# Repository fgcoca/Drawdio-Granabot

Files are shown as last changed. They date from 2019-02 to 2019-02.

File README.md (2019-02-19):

# Drawdio-Granabot
Esta versión de Drawdio es derivada de la de [**Jorge Frutos** (@JorFru)](https://twitter.com/JorFru_) realizada en [**UC3Music** (@UC3Music)](https://music.uc3m.es/) realizada cómo una práctica más de diseño de los alumnos de primer curso del Ciclo Formativo de Grado Superior de Mantenimiento Electrónico del IES Virgen de las Nieves y que ha pasado a formar parte de la exposición Play del Parque de las Ciencias de Granada. 

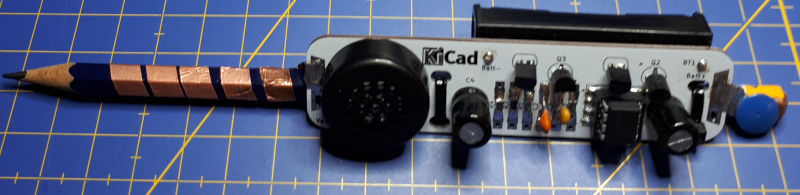
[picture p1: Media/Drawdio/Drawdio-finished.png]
Aspecto final del montaje con lápiz


 [1]: https://github.com/fgcoca/Drawdio-Granabot/blob/master/Media/Drawdio/Drawdio-finished.png

# **El diseño**
Es simplemente una versión simple de la versión de Jorge Frutos también diseñada con [Kicad 5.02](http://kicad-pcb.org/) y gracias a que su diseño es compartido de forma libre y por tanto patrimonio de la humanidad. Bajo este mismo principio de licencia CC BY SA se realiza esta versión y por tanto cualquiera de sus partes puede ser descargada, usada, cambiada, compartida y todo lo que se nos ocurra siempre bajo las condiciones establecidad en el apartado **Licencia**

Los archivos de diseño los tenemos en el enlace:

https://github.com/fgcoca/Drawdio-Granabot/tree/master/Drawdio-Granabot/KiCad%20files

Los archivos gerber están en este enlace:

https://github.com/fgcoca/Drawdio-Granabot/tree/master/Drawdio-Granabot/gerbers

las PCBs del proyecto se fabrican en [PCBWay](https://www.pcbway.com/) y están disponibles en el enlace que sigue:

https://www.pcbway.com/project/shareproject/W57189ASE4_drawdio.html

Si quieres ver lo que necesitas aquí tenemos una lista de materiales gráfica:

https://github.com/fgcoca/Drawdio-Granabot/blob/master/Drawdio-Granabot/doc/Grafic-BOM-Drawdio.pdf

Correspondiente al esquema que podemos ver en el enlace:

https://github.com/fgcoca/Drawdio-Granabot/blob/master/Drawdio-Granabot/doc/Esquema-drawdio.pdf

El aspecto de la PCB con y sin componentes por ambas caras lo vemos en las imágenes siguientes:

| Cara | Aspecto |
| --- | --- |
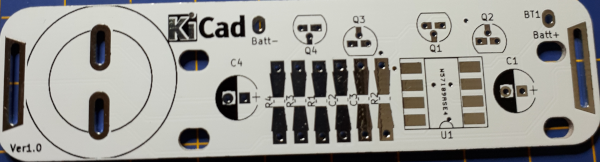
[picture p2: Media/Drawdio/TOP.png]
TOP
| TOP  |  |
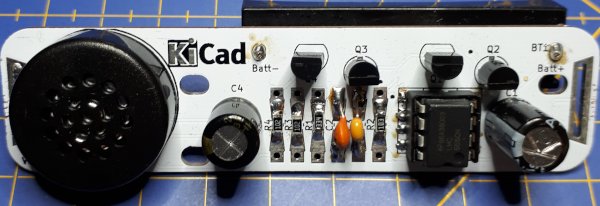
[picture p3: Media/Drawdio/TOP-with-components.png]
TOPm
| TOP montada  |  |
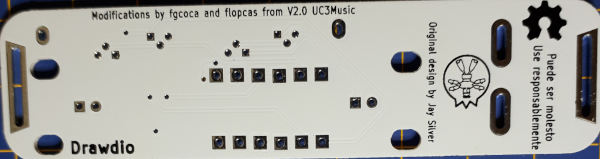
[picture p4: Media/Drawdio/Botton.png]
BOT
| BOTTON  |  |
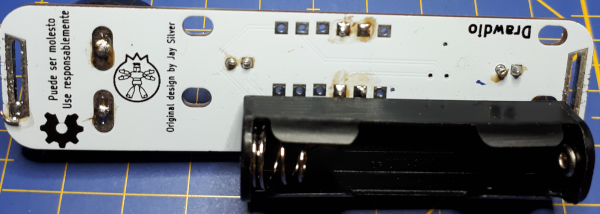
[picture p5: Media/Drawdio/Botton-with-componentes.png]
BOTm
| BOTTON montada  |  |
# **Resultado final**
Podemos ver videos del  funcionamiento en cualquiera de los enlaces siguientes:
* https://www.youtube.com/watch?v=yos-airT05g
* https://www.youtube.com/watch?v=DHovDE4k54I
* https://www.youtube.com/watch?v=34B8fDIqGeM

# **Presencia en Play**
Nuestro proyecto ha tenido el honor de ser seleccionado para formar parte de la exposición [Play. Ciencia y música](http://www.parqueciencias.com/parqueciencias/exposiciones-temporales/playcienciamusica.html) que se está celebrando actualmente (febrero de 2019) en el [Parque de las Ciencias de Granada](http://www.parqueciencias.com/parqueciencias/). Es de destacar que entre las entidades colaboradoras figura el IES Virgen de las Nieves, lo que podemos comprobar en el triptico de la exposición.

El proyecto que se lleva al parque es presentado por este cartel.

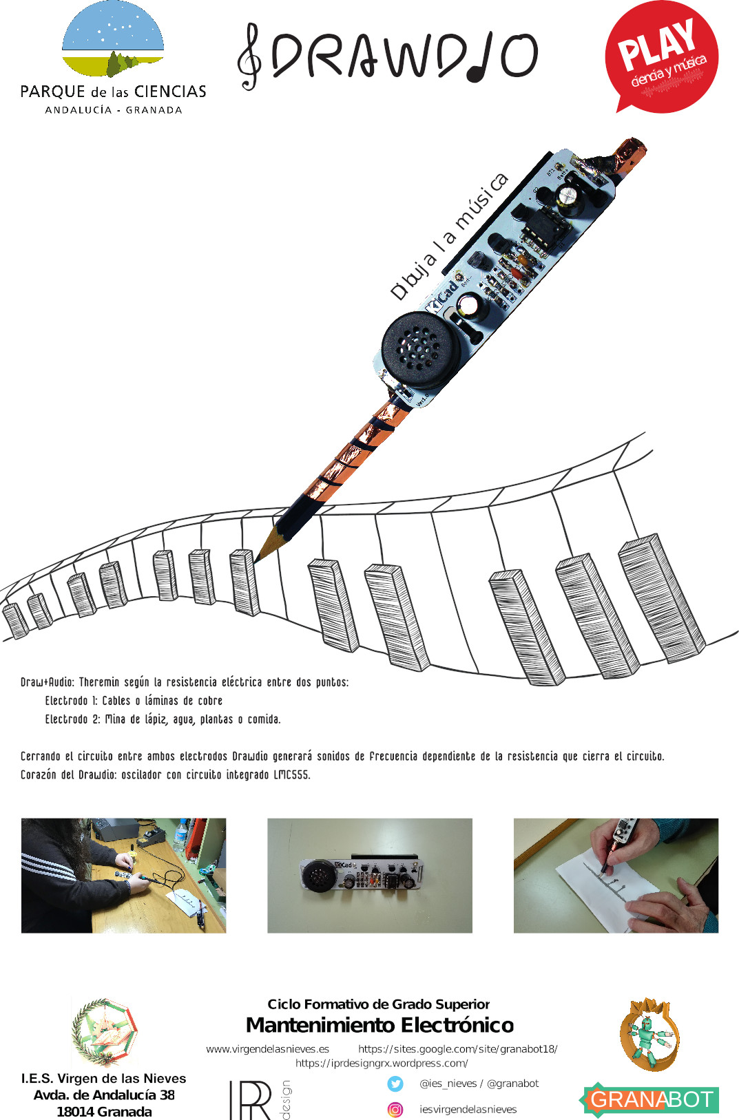
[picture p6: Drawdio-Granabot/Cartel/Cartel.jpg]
Cartel


Dicho cartel queda expuesto en el Parque y nos fotografiamos con el mismo tanto la directora del centro como yo mismo.

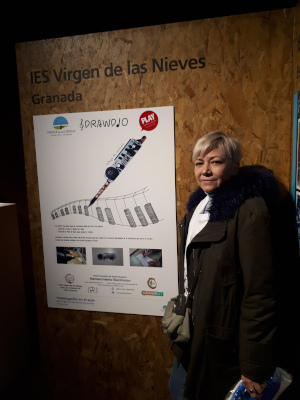
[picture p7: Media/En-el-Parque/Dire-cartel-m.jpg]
dire
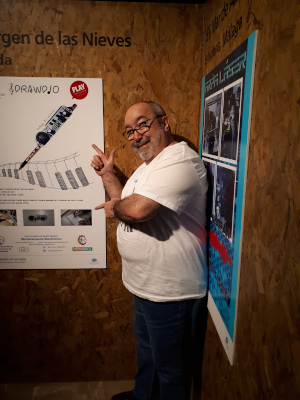
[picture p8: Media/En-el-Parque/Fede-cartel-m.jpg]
yo
|  |  |

El proyecto presentado se puede consultar en estos enlaces:
* [Proyecto Drawdio-Granabot para Play pdf](https://github.com/fgcoca/Drawdio-Granabot/blob/master/Drawdio-Granabot/doc/Proyecto-Play.pdf)
* [Proyecto Drawdio-Granabot para Play odt](https://github.com/fgcoca/Drawdio-Granabot/blob/master/Drawdio-Granabot/doc/Proyecto-Play.odt)

Para el evento de presentación del proyecto que ha tenido lugar el 14 de febrero de 2019 en el Parque se diseñó una camiseta para que el equipo de alumnos pudiera lucirla, lo que podemos apreciar en la imágenes. Todo el acto de presentación ha sido realizado por los alumnos que lo han hecho divertido e interactivo con el público asistente. Muchas gracias a todos por vuestro gran trabajo.

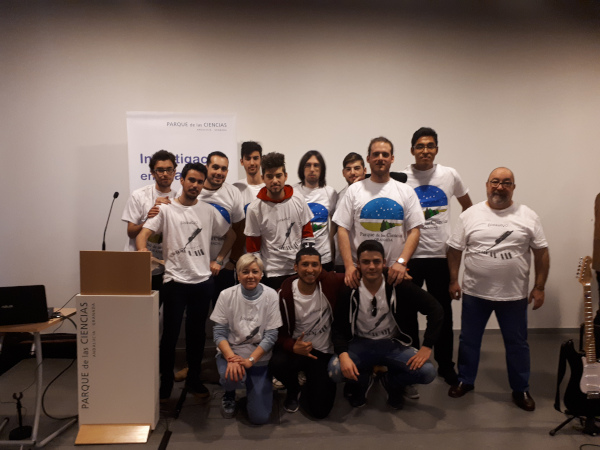
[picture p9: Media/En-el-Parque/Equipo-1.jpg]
E1

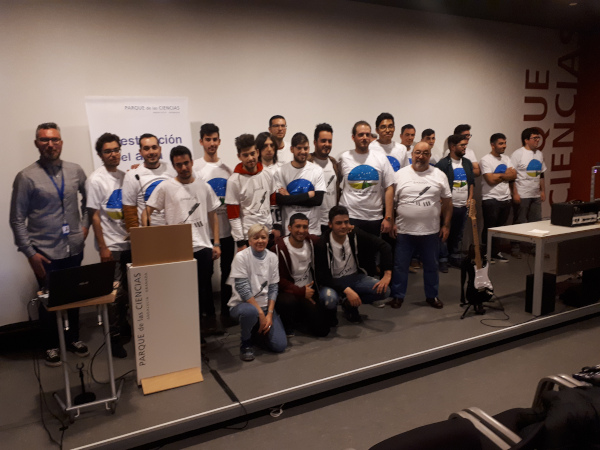
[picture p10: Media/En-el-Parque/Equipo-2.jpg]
E2

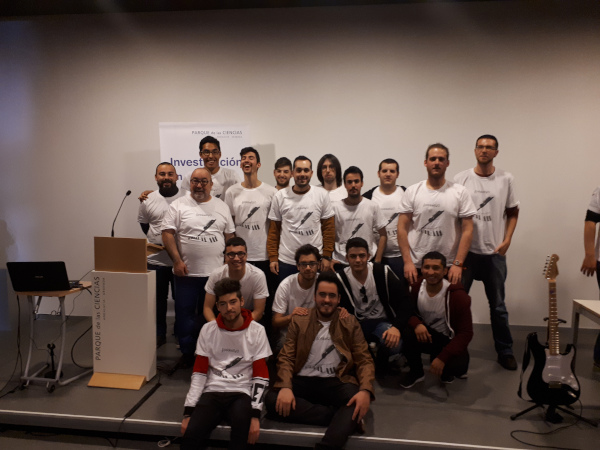
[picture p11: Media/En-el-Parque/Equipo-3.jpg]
E3

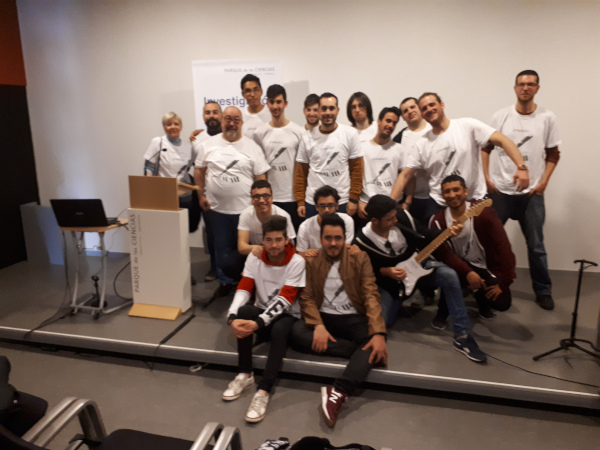
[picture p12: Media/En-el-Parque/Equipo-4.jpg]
E4


# **Autores**

[Federico Coca Caba] (https://github.com/fgcoca)

Francisco López Castro

Alumnos del grupo 1TSME

# **Créditos**
  * En primer lugar al creador original de [Drawdio](https://drawdio.com/), Jay Silver (@wakeupsilver).
  * En segundo lugar al autor de la versión en la que nos hemos basado,Jorge Frutos (@JorFru_) de [Universidad Carlos III Music](https://github.com/UC3Music/drawdio)
  * Y en tercer lugar al grupo de alumnos de 1TS de mantenimiento Electrónico del curso 18/19.

# **Licencia**
<br /> <a rel="license" href="http://creativecommons.org/licenses/by-sa/4.0/">Creative Commons Attribution-ShareAlike 4.0 International License</a>.

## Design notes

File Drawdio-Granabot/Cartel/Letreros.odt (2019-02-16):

Draw+Audio: Theremin según la resistencia eléctrica entre dos puntos:

Electrodo 1: Cables o láminas de cobre

Electrodo 2: Mina de lápiz, agua, plantas o comida.

Cerrando el circuito entre ambos electrodos Drawdio generará sonidos de frecuencia dependiente de la resistencia que cierra el circuito.

Corazón del Drawdio: oscilador con circuito integrado LMC555.

Corazón del Drawdio: oscilador con circuito integrado LMC555.

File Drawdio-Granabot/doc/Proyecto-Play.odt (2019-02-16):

Drawdio

- Cursos con los que se realizó el proyecto

Primer curso del Ciclo Formativo de Grado Superior de Mantenimiento Electrónico del IES Virgen de las Nieves de Granada.

- Como surge la idea

La idea surge de la asistencia de Federico Coca al Taller de montaje de un lápiz musical: Drawdio en la OSHDem 2018 (https://oshwdem.org/) celebrada en A Coruña el día 10 de noviembre de 2018 y que impartió el equipo UC3 Music (http://music.uc3m.es/) (grupo Music de la Universidad Carlos Tercero de Madrid).

- Toma de decisiones con el grupo de alumnos

Es bastante básica de explicar: se muestra al grupo de alumnos el funcionamiento del Drawdio montado en la OSHDem, se informa de la posibilidad de participar en el Programa Investigación en el Aula del Parque de las Ciencias con un proyecto de investigación ligado a la exposición Play. El resultado de esta propuesta es que se apunta al proyecto todo el grupo de alumnos.

- Metodología seguida

Se fundamenta en la metodología del módulo de Técnicas y Procesos de Montaje y Mantenimiento Electrónico del ciclo formativo en el que el alumnado diseña y monta circuitos.

1. Se establece el circuito electrónico para diseñar a partir de la información obtenida del repositorio drawdio (https://github.com/UC3Music/drawdio) de la UC3 Music y de la web de Jay Silver (https://drawdio.com/), su creador.
2. Los alumnos diseñan y montan la placa de circuito impreso con el circuito establecido. El aspecto final del montaje será similar al siguiente:

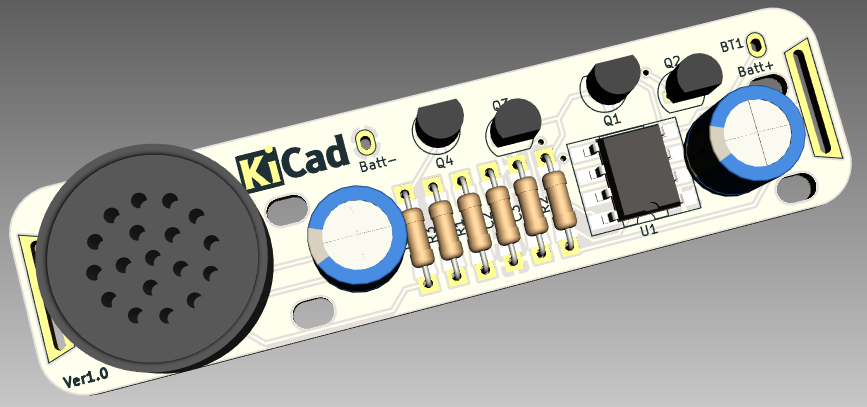
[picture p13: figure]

3. Se realizan pruebas de funcionamiento, con distintos materiales y de distintas formas, del instrumento montado. El resultado de estas pruebas se puede apreciar en el video realizado como parte de documentación del proyecto.
- Relación de alumnos participantes con indicación de los 10 miembros que conforman el equipo para la presentación en el Parque.

Orden | Nombres | Equipo
1 | Alaminos Molina, José Manuel | Presentacion
2 | Bustamante Sánchez, John Fernando | Presentacion
3 | Cara Peinado, Guillermo | Presentacion
4 | Carrillo Ureña, Rubén | Presentacion
5 | García Calvo, Manuel Enrique | Apoyo
6 | García Pérez, Javier | Apoyo
7 | Godoy Garrido, José Manuel | Apoyo
8 | López Reyes, Andrés | Presentacion
9 | López Reyes, David | Apoyo
10 | Martínez Fernández, Juan Manuel | Presentacion
11 | Montalbán Guerra, Cristóbal | Presentacion
12 | Peinado Ruiz, Ramón | Presentacion
13 | Pérez Rienda, Ismael | Presentacion
14 | Puerta Del Águila, Jesús | Presentacion
15 | Reyes Bellido, Víctor Armando | Apoyo
16 | Rodríguez Torres, Félix | Apoyo
17 | Yáñez Jerez, Francisco José | Apoyo

- Resultados obtenidos

Básicamente se trata de un pseudo instrumento músical tipo Theremin que reproduce un tono musical cuya frecuencia varía dependiendo de la resistencia eléctrica entre dos puntos.

Enrollando un cable a un lápiz tenemos un punto, otro punto es la mina del lápiz. Sujetando el Drawdio en nuestra mano pasamos a ser parte del circuito resistivo y podremos hacer sonidos de distintas frecuencias pintando con el lápiz, jugar con un chorro de agua, con comida, con otras personas y en definitiva con cualquier objeto conductor.

Es por tanto muy divertido jugar con Drawdio y llega fácilmente a todo el que lo prueba.

- Fundamentación del funcionamiento

¿Que es Drawdio?

El nombre Drawdio proviene del concepto Draw+Audio y podríamos decir que es un lápiz que “dibuja audio”

Drawdio es un pseudo instrumento musical, diseñado originalmente por Jay Silver en el MIT Media Lab (https://www.media.mit.edu/projects/drawdio/overview/). El proyecto lo encontramos en esta web (https://drawdio.com/) y en la web de Adafruit (https://learn.adafruit.com/drawdio/overview), que lo comercializa.

¿Cómo se usa?

Para que el Drawdio suene basta con completar el circuito poniendo una resistencia entre sus electrodos.

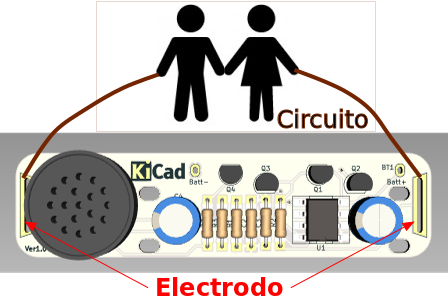
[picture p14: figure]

Esto hace que Drawdio de un sonido de una frecuencia dependiente de la resistencia que pongamos entre sus electrodos.

El montaje sobre un lápiz permite crear circuitos con dibujos ya que la mina es de grafito y este conduce la electricidad.

Otras formas de hacerlo funcionar es pintando con agua, con plantas, con varias personas, mediante el chorro de agua de un grifo, con fruta y en general mediante cualquier conductor que presente una alta impedancia.

El circuito electrónico y su descripción

Su esquema es el siguiente:

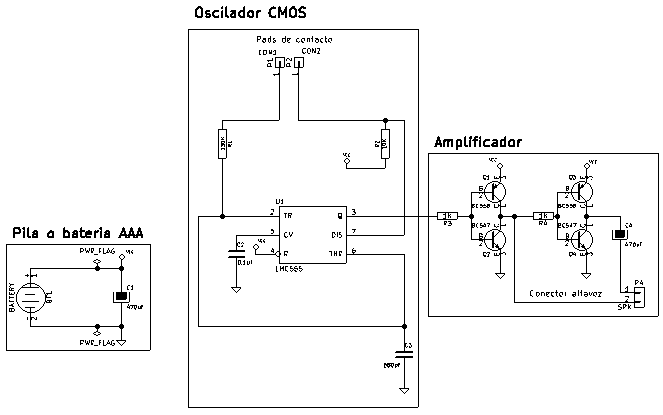
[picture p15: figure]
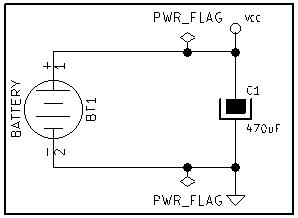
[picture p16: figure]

- Fuente de alimentación. Es la encargada de mantener todo en funcionamiento y se trata de una simple pila AAA que se coloca en un portapilas que va soldado a la PCB. En paralelo con la pila tenemos el condensador electrolítico C1 de 470 uF montado en “bypass” y se encarga de absorber cualquier rizado originado cuando el drawdio hace ruido. El circuito no está dotado de interruptor para cortar la alimentación porque esto se puede hacer fácilmente quitando la pila.

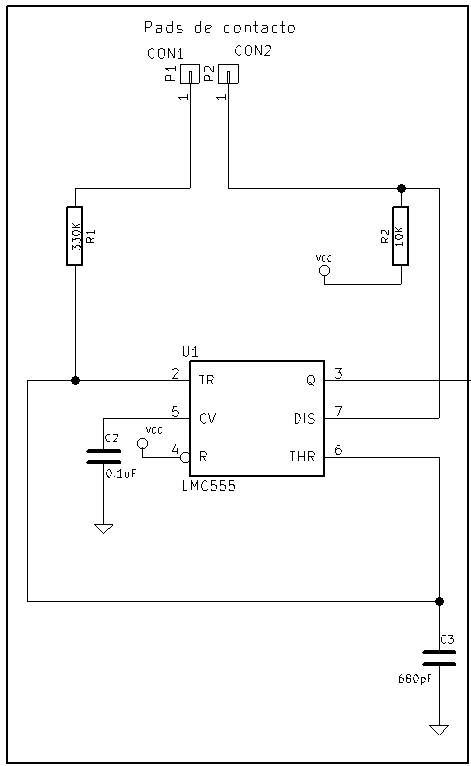
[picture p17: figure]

- El oscilador. El corazón del drawdio es un circuito integrado LMC555, que es la versión CMOS de bajo voltaje del famoso LM555. El LM555 original necesita al menos 5V para funcionar mientras que el LMC555 puede funcionar a partir de 1V.

Una de las formas más comunes de uso del 555 es como multivibrador astable, otra forma de decir un oscilador, que nos proporciona una onda cuadrada a la salida. En este enlace a Rincón Ingenieril (https://www.rinconingenieril.es/555-astable/), Enrique nos explica claramente su funcionamiento.

De forma muy resumida diremos que la frecuencia de oscilación se establece mediante dos resistencias (R1 y R2) y un condensador (C3), y como vemos los terminales de contacto ponen la resistencia que lo hace funcionar en serie con R1. El circuito integrado se encarga de cargar y descargar lentamente el condensador. Las resistencias y el condensador establecen la constante de tiempo de carga y descarga del condensador. La frecuencia de oscilación viene dada por:

f = {1.44} over {C3 cdot ( R2 + 2 cdot R1 ) }

Donde C3 es 680pF (680x10⁻¹² F), R1 es 10KΩ (10x10³ Ω) y R2 va a ser la resistencia del circuito que dibujemos más 330KΩ (330x10³ Ω). Estos valores permiten obtener rangos de frecuencia audibles con los materiales mencionados.

Para hacer la frecuencia variable podemos dejar un parámetro fijo y variar el otro. Podemos hacer el condensador variable (mas o menos lo que hace el Theremin), o hacer la resistencia variable que es el caso del Drawdio.

Cuanto mayor sea la resistencia más grave será el sonido y cuanto menor más agudo.

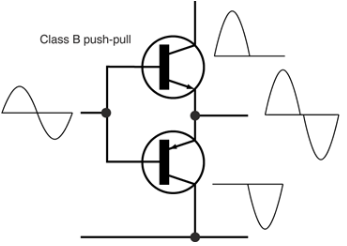
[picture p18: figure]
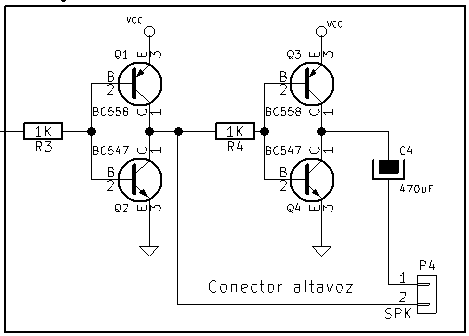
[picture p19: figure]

- Amplificador. Basa su funcionamiento en el de los amplificadores push-pull de clase B, que se constituyen a partir de dos transistores complementarios.

Cada etapa push-pull será capaz de entregar una señal de salida con amplitud máxima igual a la tensión de alimentación que recordemos es la de una pila AAA, o sea 1.5V, luego la salida será de 1.5Vpp.

La etapa de salida en modo puente se consiguen 3Vp-p a partir de una pila de 1.5V. La configuración recibe el nombre de puente porque se parece a los Puente en H que se emplean para controlar el movimiento adelante/atrás de los motores de corriente continua.

El circuito tiene dos estados, uno cuando la salida del oscilador es alta y tendremos nivel de salida de 1.5Vpp en la patilla 2 del altavoz y cero en la 1, y otro para cuando es baja que tendremos 1.5Vpp en la patilla 1 del altavoz mientras que la 2 es cero. En total tenemos una tensión de 3Vpp entre las patillas del altavoz.

La potencia máxima que se desarrollado por cada etapa será:

P= { V^{2}} over {R} = { 1.5^{2}} over {8} = 0,28125 W simeq 280 mW

Tendremos entonces una potencia total algo superior a 0.5W.

El condensador C4 tiene como misión impedir el paso de la corriente continua al altavoz. El valor de C4 se establece para conseguir el máximo volumen posible con la forma parecida a un diente de sierra que tenemos a la salida. Si bajamos su valor vamos a reducir la potencia consumida pero cambiará el timbre del sonido. Si ponemos un valor mayor no conseguiremos mayor volumen aunque si aumentaremos el consumo.

La amplitud de la onda es fija, por lo que no podremos ajustar el volumen.

- Logros obtenidos

Es bastante evidente que el alumnado se ha implicado completamente en la realización del trabajo y se ha favorecido mucho el trabajo en equipo así como diversificar tareas destinadas a documentar el trabajo, encontrar otras aplicaciones y proponer mejorás técnicas.

- Reflexión final

Trabajo novedoso, interesante, instructivo, educativo, original, apasionante, muy beneficioso, emprendedor y favorecedor del trabajo en equipo son algunos de los adjetivos que más hemos oído durante su creación.

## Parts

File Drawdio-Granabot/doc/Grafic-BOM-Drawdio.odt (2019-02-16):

Lista de materiales de Drawdio Granabot

Ref | Cant | Valor | Imagen | | | Observaciones
R1 | 1 | 330k | | | | 1/4W inserción o 1206 SMD
R2 | 1 | 10k
R3,R4 | 2 | 1k
C1, C4 | 2 | 470uF/25V | | | | 6.3 mm de diámetro

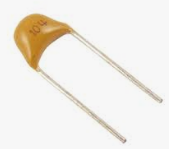
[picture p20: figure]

C2 | 1 | 0.1uF | | | | Cerámicos tipo lenteja o 1206 SMD
C3 | 1 | 680pF
Q2, Q4 | 2 | BC547 | | | | TO92 o SOT23
Q1, Q3 | 2 | BC558

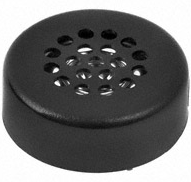
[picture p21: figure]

P4 | 1 | Speaker 8R | | | | Mini altavoz de 8 Ohm y 100 mW
U1 | 1 | LMC555 | | | | Formato DIP 8 pines. Hay que asegurar que es CMOS

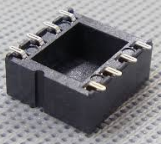
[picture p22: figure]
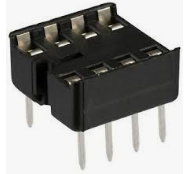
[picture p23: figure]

| 1 | Zócalo DIP8 | | | | Si es cómo el de la imagen se puede adaptar doblando los pines
BT1 | 1 | Battery | | | | tipo AAA (LR03) de 44,5 x10,5 mm y 1,5 V
| 1 | Portapilas | | | | Debe ser de 1 elemento para PCB y para pilas AAA
P1,P2 | 1 | Cinta cobre | | | | Un trocito con la longitud de un lápiz nuevo

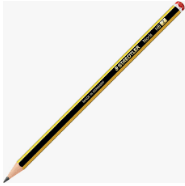
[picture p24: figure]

| 1 | Lápiz
| 1 | Chincheta | | | | Metálica completa

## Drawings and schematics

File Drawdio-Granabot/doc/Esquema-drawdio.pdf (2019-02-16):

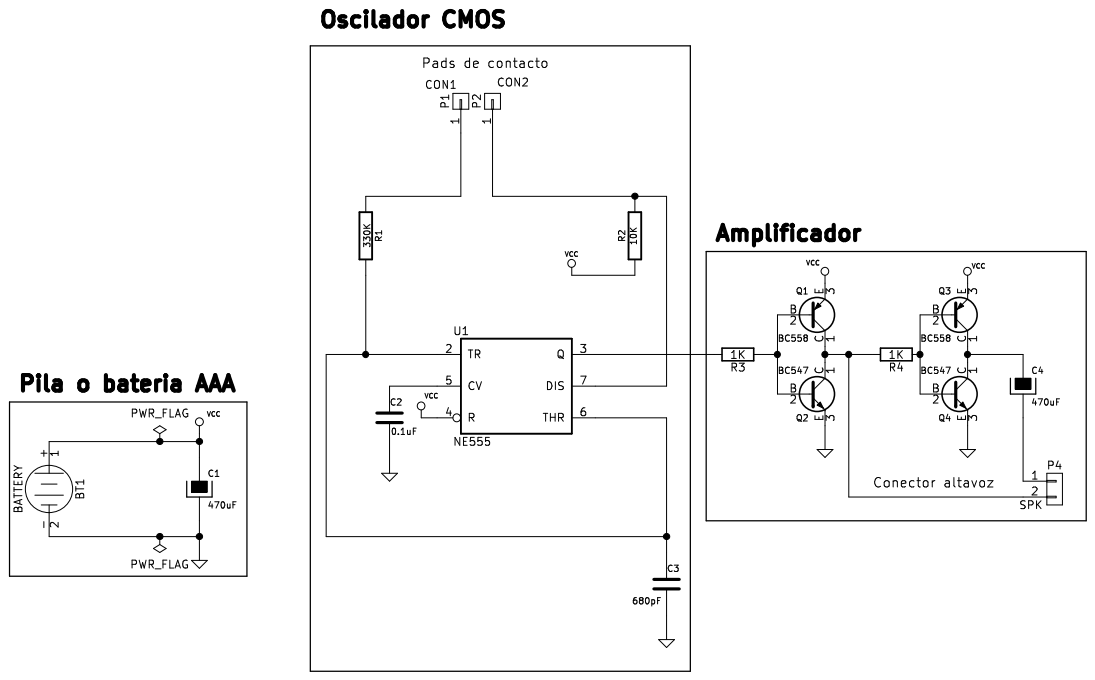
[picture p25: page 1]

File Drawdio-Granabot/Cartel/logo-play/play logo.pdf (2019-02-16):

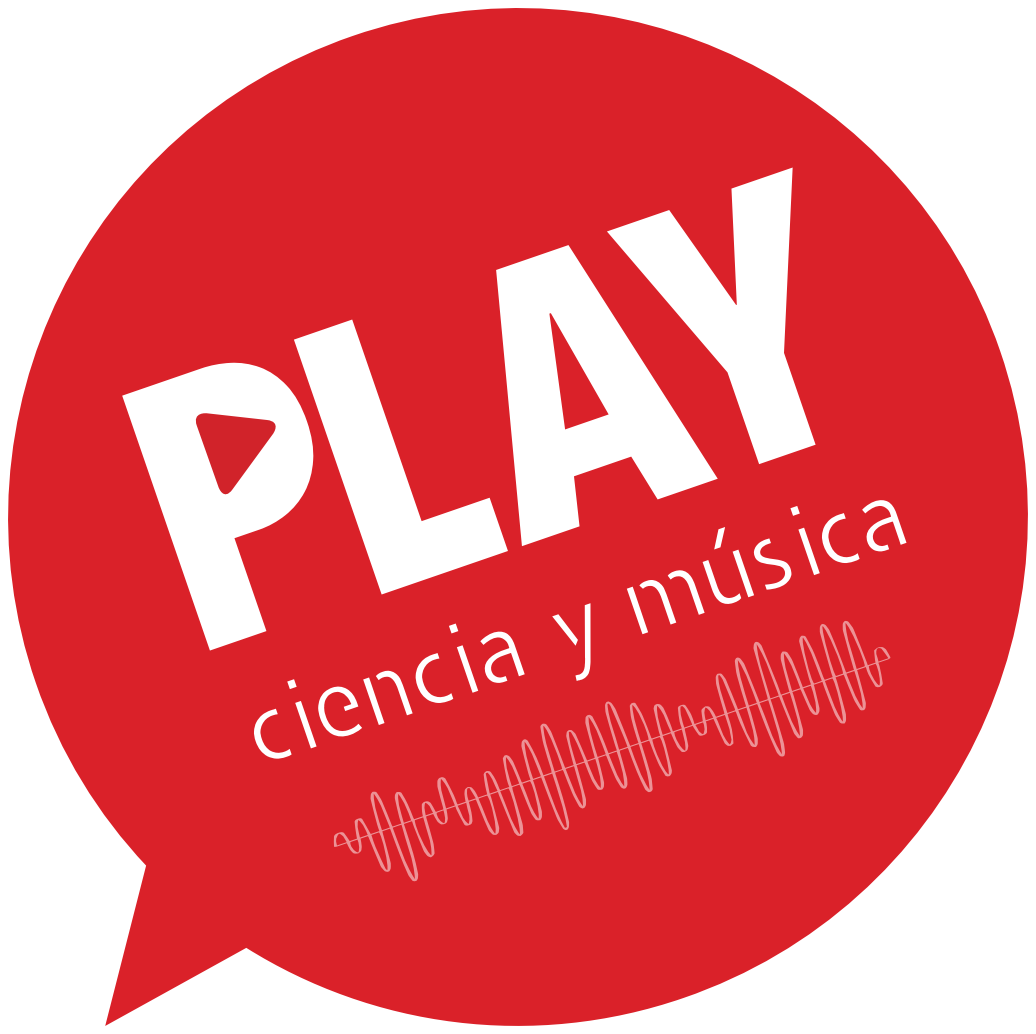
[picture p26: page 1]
ciencia y música

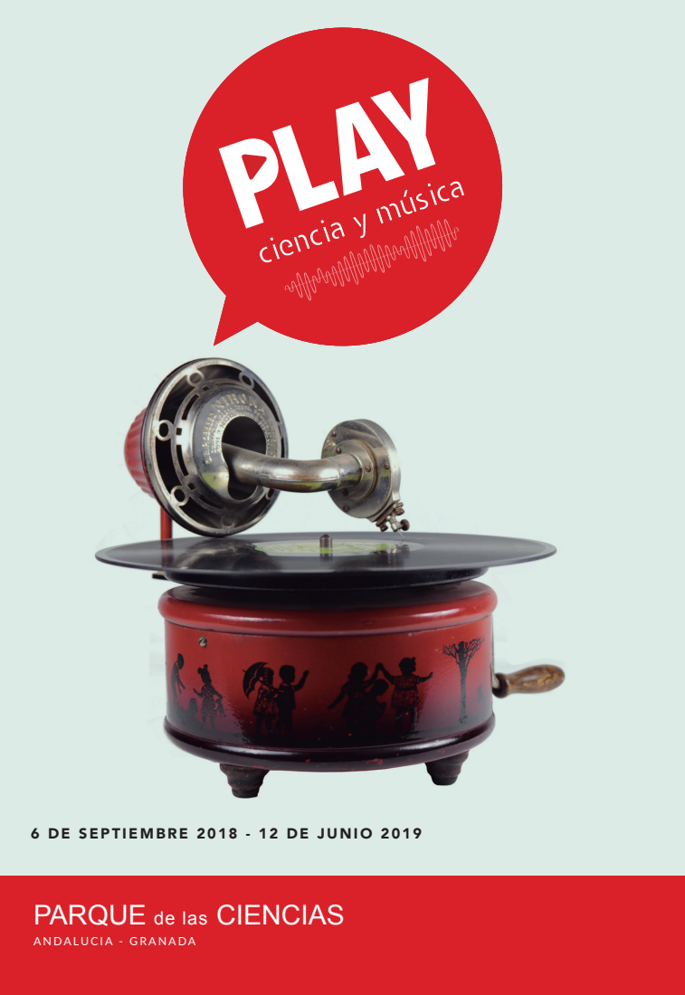
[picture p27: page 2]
ANDALUCIA - GRANADA; ciencia y música

6 DE SEPTIEMBRE 2018 - 12 DE JUNIO 2019

PARQUE de las CIENCIAS

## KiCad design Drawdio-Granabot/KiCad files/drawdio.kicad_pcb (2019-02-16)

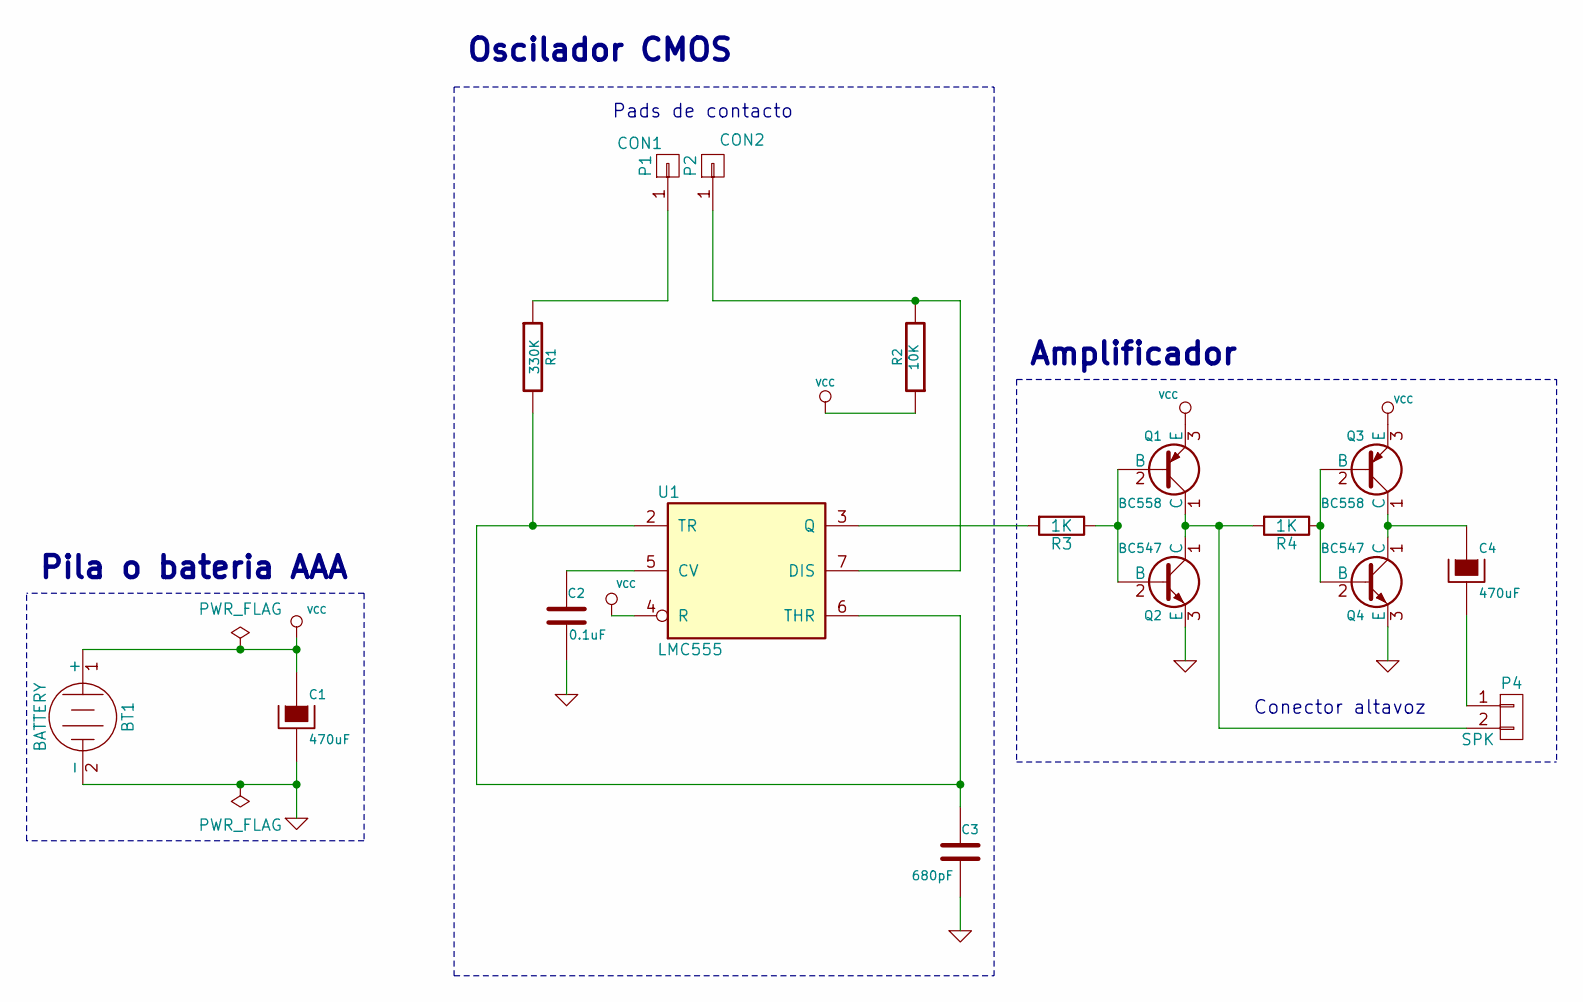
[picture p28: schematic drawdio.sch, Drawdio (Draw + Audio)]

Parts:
BT1: BATTERY; AAA_cell_holder
C1, C4: 470uF; CP_Radial_D6.3mm_P2.50mm
C2: 0.1uF; Resistor_SMD+THTuniversal_0805to1206_RM10_HandSoldering
C3: 680pF; Resistor_SMD+THTuniversal_0805to1206_RM10_HandSoldering
P1: CON1; Drawdio_conn
P2: CON2; Drawdio_conn
P4: SPK; RS_mini_speaker_724-3100
Q1, Q3: BC558; TO-92_Molded_Narrow-plus-SOT-23
Q2, Q4: BC547; TO-92_Molded_Narrow-plus-SOT-23
R1: 330K; Resistor_SMD+THTuniversal_0805to1206_RM10_HandSoldering
R2: 10K; Resistor_SMD+THTuniversal_0805to1206_RM10_HandSoldering
R3, R4: 1K; Resistor_SMD+THTuniversal_0805to1206_RM10_HandSoldering
U1: LMC555; DIP-8_W8.89mm_SMDSocket_LongPads

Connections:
GND: BT1.2 (-), C1.2, C2.2, C3.2, Q2.3 (E), Q4.3 (E), U1.1 (GND)
unnamed: C2.1, U1.5 (CV)
unnamed: C3.1, R1.2, U1.2 (TR), U1.6 (THR)
unnamed: C4.1, Q3.1 (C), Q4.1 (C)
unnamed: C4.2, P4.1
unnamed: P1.1, R1.1
unnamed: P2.1, R2.2, U1.7 (DIS)
unnamed: P4.2, Q1.1 (C), Q2.1 (C), R4.2
unnamed: Q1.2 (B), Q2.2 (B), R3.1
unnamed: Q3.2 (B), Q4.2 (B), R4.1
unnamed: R3.2, U1.3 (Q)
VCC: BT1.1 (+), C1.1, Q1.3 (E), Q3.3 (E), R2.1, U1.4 (R), U1.8 (VCC)

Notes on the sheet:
Conector altavoz
Amplificador
Pila o bateria AAA
Pads de contacto
Oscilador CMOS

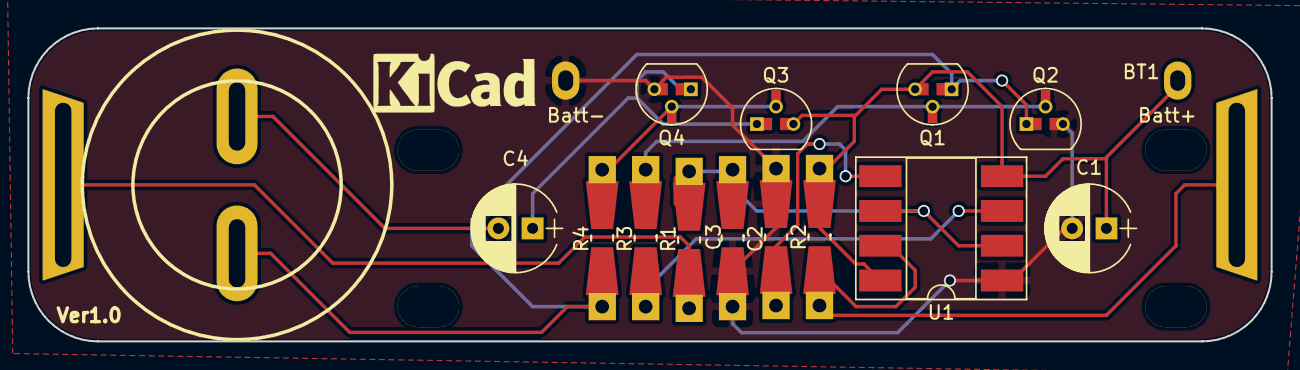
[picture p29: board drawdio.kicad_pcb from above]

Board: 2 copper layers, 90.8 x 22.9 mm, 18 parts (0 on the bottom side), 12 nets.

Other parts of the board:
SPK: LOGO; Fiducial_1mm_Dia_2.54mm_Outer_CopperTop
